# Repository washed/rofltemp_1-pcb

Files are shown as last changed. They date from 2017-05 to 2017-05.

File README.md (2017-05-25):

# rofltemp_1-pcb

This is the circuit schematic and board layout project for the ROFLtemp-1 multi-purpose
RTD thermometer.
# WARNING! DO NOT BUILD WITH THESE DESIGN FILES! Several stupid errors are in this layout that will be corrected in the final version!

# Features:
 - High accuracy RTD (PT1000) 4-wire measurement
 - Filtering for measurement inputs for high immunity in noisy enviroments (I'm looking at you, induction stoves!)
 - USB connectivity for LiPo battery charging, firmware update and data-logging
 - High brightness 7-segment LED display for good readability even in daylight
 - 0.1° resolution on 3-digit display -> above 99.9 displayed resolution will drop to 1°
 - Integrated fast charging, power path management and buck/boost regulator for efficient battery use and continous operation if plugged in

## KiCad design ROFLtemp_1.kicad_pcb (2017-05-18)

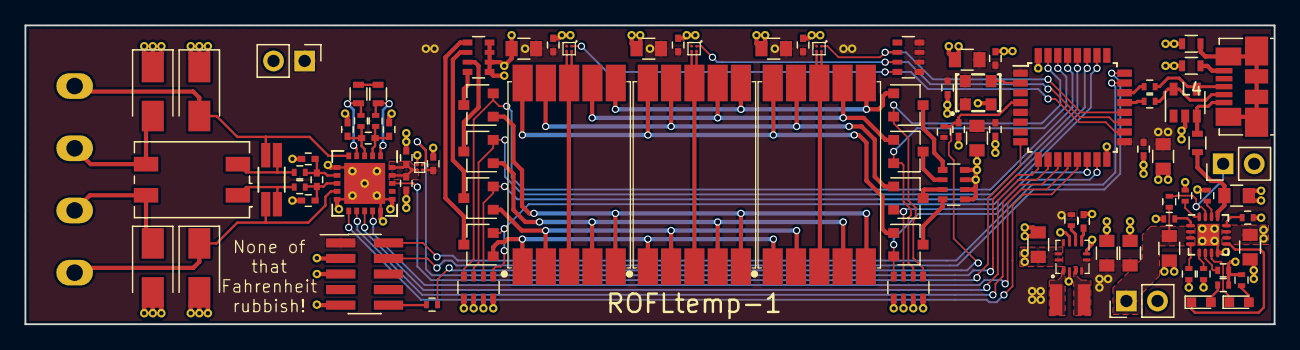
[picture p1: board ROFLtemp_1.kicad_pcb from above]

Board: 2 copper layers, 102.0 x 24.4 mm, 96 parts (0 on the bottom side), 81 nets.

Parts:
C1: 1u 25V; C_0805
C2, C3, C5, C17, C19, C21, C22, C24, C25, C27, C29: 100n 16V; C_0402
C4, C6: 4u7 25V; C_0805
C7: 10u 25V; C_0805
C8, C11, C12, C13: 1n; C_0402
C9, C10: 10n; C_0402
C14: 1n3 16V; C_0402
C15, C16: 10u 6V3; C_0805
C18, C20, C23, C26, C28, C30: 1u 16V; C_0805
D1, D2: LED_ALT; LED_0603
D3, D4, D5, D6: D_TVS; D_SMA_Standard
D7: SP0504BAHT; SOT-23-5
J1: USB_OTG; USB_Micro-B_Molex_47346-0001
J2: CONN_02X05; Pin_Header_Straight_2x05_Pitch1.27mm_SMD
L1: LQM2HPN1R5MG0L; Neosid_Inductor_SM-NE29_SMD1008
L2: WE-SL2; L_CommonMode_Wuerth_WE-SL2
L3, L4, L5: WE-CBF 742792651; L_0603
P1, P2: CONN_01X02; PM_5.08_2
P3, P4: CONN_01X02; Pin_Header_Straight_1x02_Pitch2.54mm
Q1: ASEM1
Q2, Q3, Q5, Q6, Q8, Q9, Q10, Q12: DMN1019USN; SC-59
Q4, Q7, Q11: DMP1100UCB4; X2-WLB0808-4
R1, R2, R6, R9, R21: 10k; R_0402
R3: DNI; R_0402
R4, R5, R10, R18: 100k; R_0402
R7, R8: 1k5; R_0402
R11, R12, R13, R14: TBD R; R_0402
R15: RTD PT1000 DNI; R_1206_RTD_SPLITPADS
R16: 2k 0.01%; R_0603
R17: 2K 0.01%; R_0603
R19, R20: 15R; R_0402
R22: 0R; R_0402
RN1, RN3, RN5: 10k; R_Array_Convex_4x0603
RN2, RN4: 68R; R_Array_Convex_4x0603
SW1: SW_SPST; Pin_Header_Straight_1x02_Pitch2.54mm
U1: TPS2290x; TPS229x
U2: BQ24079; QFN-16-1EP_3x3mm_Pitch0.5mm
U3: MAX31865; QFN-20-1EP_5x5mm_Pitch0.65mm
U4: STM32F042K6Tx; LQFP-32_7x7mm_Pitch0.8mm
U5: TPS63051; RWM0012A
U6, U7, U8: 7SEGMENT_CA; VDMx10.0

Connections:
+3V3: C2.1, C15.1, C16.1, C17.1, C18.1, C19.1, C20.1, C21.1, C23.1, C24.1, C25.1, C26.1, C27.1, C28.1, C29.1, C30.1, J2.1, P4.1, Q1.1, Q1.4, Q4.2, Q7.2, Q11.2, R18.2, R21.2, RN5.1, RN5.2, RN5.3, RN5.4, U1.A1, U4.1, U4.5, U4.17, U5.4, U5.5
+5V: C1.1, L5.1, U2.13
+BATT: C4.1, P3.1, R1.2, U2.2, U2.3
/7SEG_0: Q11.1, RN5.8, U4.18
/7SEG_1: Q4.1, RN5.7, U4.19
/7SEG_2: Q7.1, RN5.6, U4.20
/7SEG_A: Q2.2, RN3.6, U4.30
/7SEG_B: Q3.2, RN3.5, U4.31
/7SEG_C: Q5.2, RN1.7, U4.28
/7SEG_D: Q6.2, RN1.6, U4.27
/7SEG_DP: Q12.2, RN1.8, U4.29
/7SEG_E: Q8.2, RN1.5, U4.26
/7SEG_F: Q9.2, RN3.7, U4.14
/7SEG_G: Q10.2, RN3.8, U4.15
/OSC_IN: Q1.3, U4.2
/SPI1_CS: U3.13, U4.10
/SPI1_DR: U3.18, U4.8
/SPI1_MISO: U3.14, U4.12
/SPI1_MOSI: U3.11, U4.13
/SPI1_PWR: U1.B1, U4.9
/SPI1_SCK: U3.12, U4.11
/SYS_NRST: C22.1, R21.1, R22.2, U4.4
/SYS_SWCLK: J2.4, U4.24
/SYS_SWDIO: J2.2, U4.23
/USB_DM: D7.5, J1.2, R19.2
/USB_DP: D7.4, J1.3, R20.2
GND: C1.2, C2.2, C3.2, C4.2, C5.2, C6.2, C7.2, C8.1, C11.2, C12.1, C13.2, C14.2, C15.2, C16.2, C17.2, C18.2, C19.2, C20.2, C21.2, C22.2, C23.2, C24.2, C25.2, C26.2, C27.2, C28.2, C29.2, C30.2, D3.1, D4.2, D5.1, D6.2, D7.2, J2.3, J2.5, J2.9, L3.2, L4.2, P3.2, P4.2, Q1.2, R2.1, R3.1, R4.1, R5.1, R6.1, R9.1, RN1.1, RN1.2, RN1.3, RN1.4, RN2.1, RN2.2, RN2.3, RN2.4, RN3.1, RN3.2, RN3.3, RN3.4, RN4.1, RN4.2, RN4.3, RN4.4, SW1.2, U1.B2, U2.8, U2.17, U3.6, U3.10, U3.15, U3.16, U3.21, U4.16, U4.32, U5.2, U5.6, U5.9
unnamed: C3.1, C5.1, U1.A2, U3.19, U3.20
unnamed: C6.1, C7.1, R7.2, R8.2, R10.2, U2.10, U2.11, U5.11, U5.12
unnamed: C8.2, C9.1, R11.1, U3.2
unnamed: C10.1, C13.1, R13.1, U3.7
unnamed: C10.2, C11.1, R14.1, U3.8
unnamed: C9.2, C12.2, R12.1, U3.3
unnamed: C14.1, U5.7
unnamed: D1.1, U2.7
unnamed: D1.2, R7.1
unnamed: D2.1, U2.9
unnamed: D2.2, R8.1
unnamed: D3.2, L2.2, P1.1, R13.2, R15.1, U3.5
unnamed: D4.1, L2.1, P2.2, R14.2, R15.2, U3.9
unnamed: D5.2, L2.3, P1.2
unnamed: D6.1, L2.4, P2.1
unnamed: D7.3, J1.1, L5.2
unnamed: J1.5, L4.1
unnamed: J1.6, L3.1
unnamed: J2.10, R22.1
unnamed: L1.1, U5.1
unnamed: L1.2, U5.3
unnamed: Q2.1, U6.7, U7.7, U8.7
unnamed: Q2.3, RN2.6
unnamed: Q3.1, U6.6, U7.6, U8.6
unnamed: Q3.3, RN2.5
unnamed: Q4.3, Q4.4, U6.3, U6.8
unnamed: Q5.1, U6.4, U7.4, U8.4
unnamed: Q5.3, RN4.7
unnamed: Q6.1, U6.2, U7.2, U8.2
unnamed: Q6.3, RN4.6
unnamed: Q7.3, Q7.4, U7.3, U7.8
unnamed: Q8.1, U6.1, U7.1, U8.1
unnamed: Q8.3, RN4.5
unnamed: Q9.1, U6.9, U7.9, U8.9
unnamed: Q9.3, RN2.7
unnamed: Q10.1, U6.10, U7.10, U8.10
unnamed: Q10.3, RN2.8
unnamed: Q11.3, Q11.4, U8.3, U8.8
unnamed: Q12.1, U6.5, U7.5, U8.5
unnamed: Q12.3, RN4.8
unnamed: R1.1, SW1.1, U2.15
unnamed: R2.2, U2.4
unnamed: R3.2, U2.14
unnamed: R4.2, U2.12
unnamed: R5.2, U2.16
unnamed: R6.2, U2.1
unnamed: R9.2, U2.5
unnamed: R10.1, U2.6
unnamed: R11.2, R16.1, U3.1
unnamed: R12.2, R17.1, U3.4
unnamed: R16.2, R17.2
unnamed: R18.1, U5.8
unnamed: R19.1, U4.21
unnamed: R20.1, U4.22

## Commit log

2017-04-19 Begin power management circuitry
    [ROFLtemp_1.sch]
2017-04-27 Started adding battery and 7Seg circuit
    [ROFLtemp_1.sch]
2017-04-29 Add some more circuitry
    [ROFLtemp_1.sch]
2017-04-30 Finish schematic, start layout
    [ROFLtemp_1.kicad_pcb, ROFLtemp_1.sch]
2017-05-02 Finish first prototype version
    [ROFLtemp_1.kicad_pcb, ROFLtemp_1.sch]
2017-05-18 Improve readability for PCB population
    [ROFLtemp_1.kicad_pcb]
